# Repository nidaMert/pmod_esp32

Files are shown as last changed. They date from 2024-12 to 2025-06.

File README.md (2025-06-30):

# MuhTas-1 Project PMOD ESP32

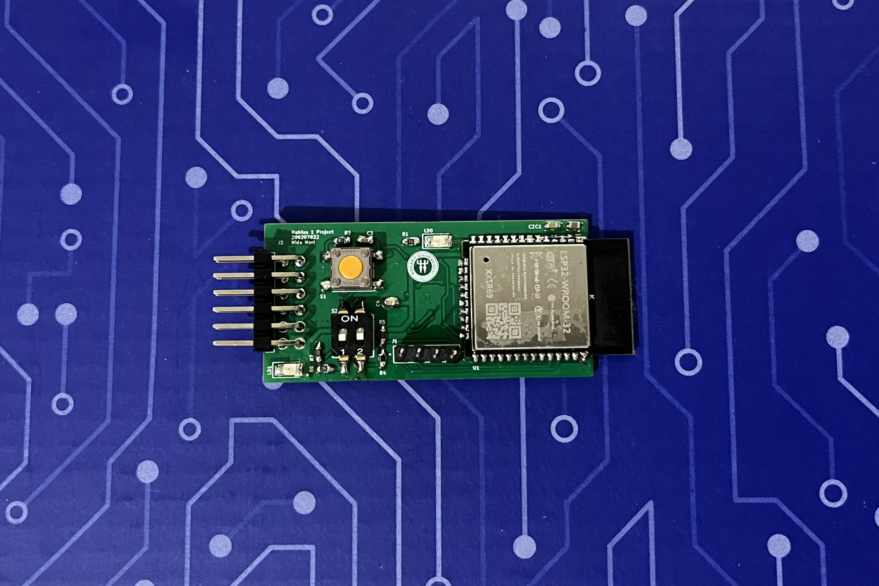
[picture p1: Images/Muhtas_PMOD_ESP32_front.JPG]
image alt


**Overview**
---
This project focuses on the design and testing of a custom 2-layer PMOD ESP32 module, closely resembling Digilent's PMOD ESP32 product. The PMOD ESP32 module provides Wi-Fi and Bluetooth connectivity, making it an ideal choice for embedded systems and IoT applications that require wireless communication. The module is designed to interface seamlessly with microcontrollers and FPGAs via the PMOD interface, enabling rapid prototyping and testing.

The functionality of the designed PMOD ESP32 board will be verified by sending AT commands through an STM32 microcontroller.

This repository includes:
- **Hardware Design Files** for the custom PMOD ESP32 board.
- **Firmware and Documentation** for the ESP32-WROOM-32 module.
- **Testing Examples** demonstrating STM32-based communication using AT commands.

The project serves as a practical solution for developers seeking an easy-to-use wireless module for their embedded systems.

**Project Structre**
---
- **Documentation/**: Contains connection diagrams for STM32-PMOD ESP32 / PMOD ESP32-USB TTL Converter and datasheets for components.
- **Firmware/ESP32-WROOM-32-AT-V3.4.0.0/**: Includes ESP32 Wroom 32 firmware files, user guides, release notes, and other documentation related to ESP32-WROOM-32-AT V3.4.0.0.
- **Hardware Designs/**: Contains hardware design files for the PMOD ESP32 module in 2-layer and 4-layer configurations.
- **Images/**: The photos of the PMOD ESP32 module before and after soldering, as well as the photos of the completed connections, are located in this folder.
- **Library/**: The libraries of components that are necessary for the project but are not available in the KiCad library are located in this folder.
- **STM32 Applications/**: Includes STM32 Cube IDE application and logic analyzer test results.
- **.gitmodules**: Configuration file for Git submodules.
- **README.md**: This file provides an overview of the project and instructions.

**Version Comparison**
---
- Between v0.1 and v0.2 of the PCB, the only difference lies in the routing; in v0.2, the placement and number of vias were optimized to enhance signal integrity and streamline the overall layout.
- **Branch Links of Versions** :  
[PMOD_ESP32_2Layers_v0.1](https://github.com/nidaMert/pmod_esp32/tree/PMOD_ESP32_2Layers_v0.1): Initial version of the PCB.  
[PMOD_ESP32_2Layers_v0.2](https://github.com/nidaMert/pmod_esp32/tree/PMOD_ESP32_2Layers_v0.2): Updated version with optimized routing.

**Connection Diagrams**
---
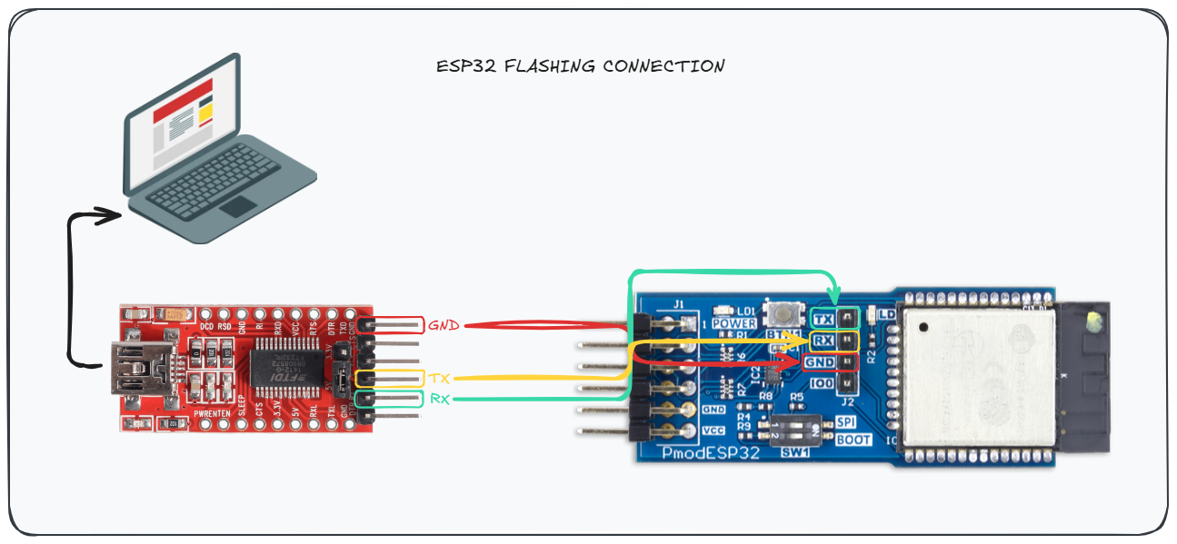
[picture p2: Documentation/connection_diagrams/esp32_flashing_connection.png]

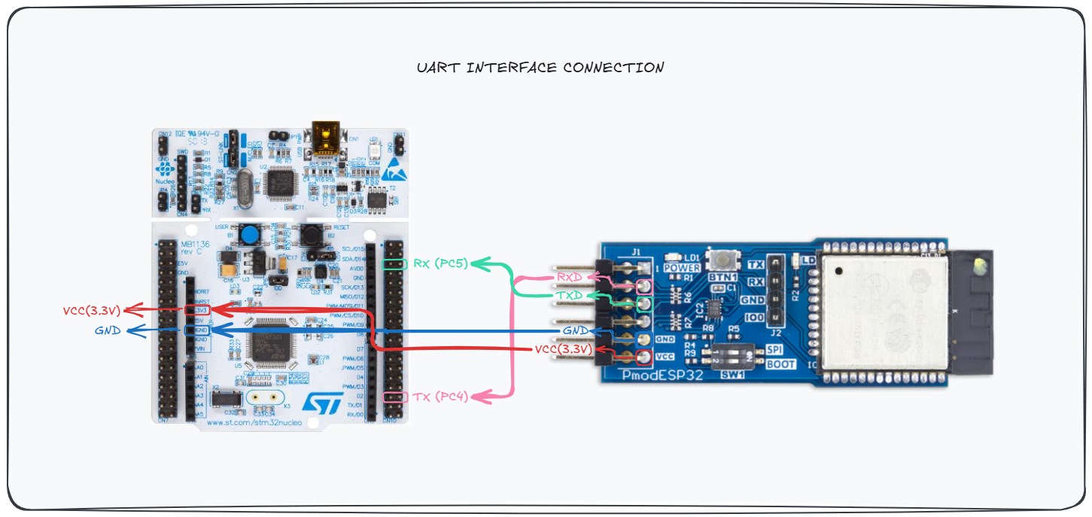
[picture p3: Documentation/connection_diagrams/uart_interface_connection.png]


**References**
---
This project was developed based on the Digilent product: [[here](https://digilent.com/reference/pmod/pmodesp32/start?redirect=1)]. The design and implementation closely resemble this product, with some modifications.

**Educational Use Only**
---
All contents of this project are shared solely for individual learning and academic evaluation. Copying, redistribution, or reuse in other projects is **strictly prohibited**.

**© Copyright**
---
**Copyright (c) 2025 Nida Mert**

All rights reserved. The source files, documentation, and visuals are provided strictly for educational and personal review purposes only.

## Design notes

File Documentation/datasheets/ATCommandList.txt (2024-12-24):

---Basic AT Commands---
AT						//Test AT startup
AT+RST						//Restart a modüle
AT+GMR						//Check version information

---Wi-Fi AT Commands---
AT+CWLAP					//List all available APs.
AT+CWQAP					//Disconnect from an AP.
AT+CWSTATE?					//Query the Wi-Fi state and Wi-Fi info
						//current Wi-Fi state
				  			0: ESP32 station has not started any Wi-Fi connection.
				  			1: ESP32 station has connected to an AP, but does not get an IPv4 address yet.
				  			2: ESP32 station has connected to an AP, and got an IPv4 address.
				  			3: ESP32 station is in Wi-Fi connecting or reconnecting state.
				  			4: ESP32 station is in Wi-Fi disconnected state.
AT+CWMODE?					//Query the Wi-Fi mode of ESP32.
						//<mode>
				 			0: Null mode. Wi-Fi RF will be disabled. The ESP32 will automatically connect to an AP if the configuration to connect to the AP has already been saved in flash before.
				  			1: Station mode.
				  			2: SoftAP mode.
				  			3: SoftAP+Station mode.
AT+CWMODE=<mode>
AT+CWJAP?					//Query the AP to which the ESP32 Station is already connected.
AT+CWJAP=[<ssid>],[<pwd>]			//Connect an ESP32 station to a targeted AP.
AT+CWJAP					//Connect an ESP32 station to a targeted AP with last Wi-Fi configuration.
						//<error code>
				  			1: connection timeout.
				  			2: wrong password.
				  			3: cannot find the target AP.
				  			4: connection failed.
				  			others: unknown error occurred.
AT+CIPV6=1					// At present, ESP-AT is mainly based on IPv4 network, supplemented by IPv6 network.To get an IPv6 address, we need to set it.
AT+CIPSTA?					//Query the IP address of the ESP32 Station.

---TCP/IP AT Commands---
AT+CIPSTART					//Establish TCP Connection
						//Single connection (AT+CIPMUX=0):
				  			AT+CIPSTART=<"type">,<"remote host">,<remote port>[,<keep_alive>][,<"local IP">][,<timeout>]
				  			Multiple Connections (AT+CIPMUX=1):
				  			AT+CIPSTART=<link ID>,<"type">,<"remote host">,<remote port>[,<keep_alive>][,<"local IP">][,<timeout>]
AT+CIPSTATE?					//Obtain the TCP/UDP/SSL Connection Information

---TCP Client Commands---
AT+CIPSTART="TCP","192.168.1.57",8080		//TCP Client olarak bağlan
AT+CIPMODE=1					//Transparan mod aktif
AT+CIPSEND					//Veri gönder
"+++"						//Transparan komut göndermeyi bitir.
AT+CIPCLOSE					//Bağlantıyı kes.

---TCP Server Commands---
AT+CIPMUX=1					//Birden fazla bağlantıya izin ver.
AT+CIPSERVER=1,80				//80 numaralı TCP portunu aç
AT+CIPSEND=0,10					//10 Byte veri gönder
AT+CIPCLOSE=0					//bağlantıyı kes

---UDP Client/Server Commands---
AT+CIPSTART="UDP","192.168.1.57",1001,2001,0
AT+CIPMODE=1					//Transparan mod aktif
AT+CIPSEND					//Veri gönder
"+++"						//Transparan komut göndermeyi bitir.
AT+CIPCLOSE					//Bağlantıyı kes.

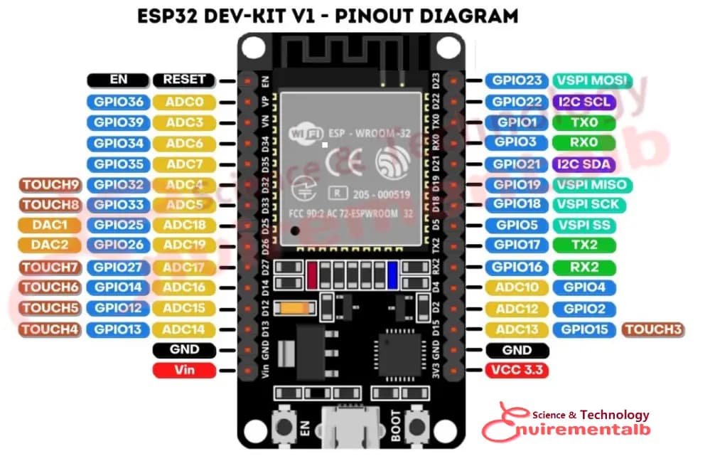
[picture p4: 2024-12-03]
Documentation/datasheets/esp32 devkit pinout.jpeg

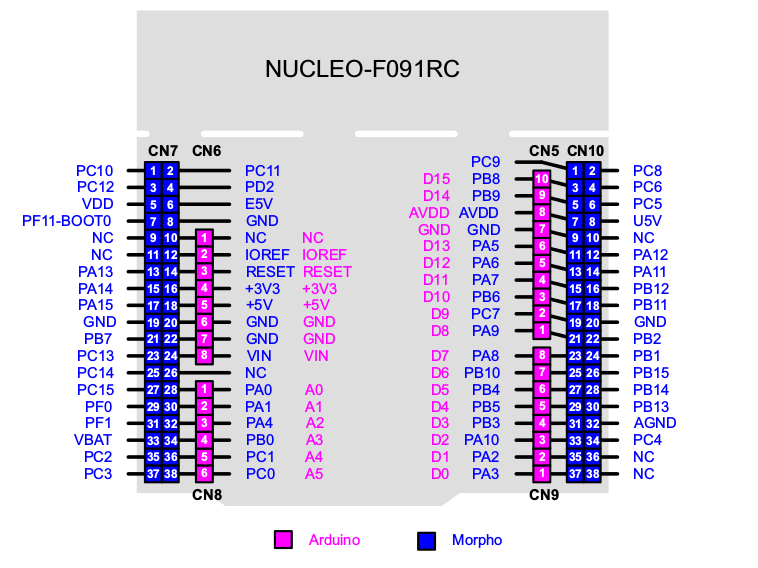
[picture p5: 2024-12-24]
Documentation/datasheets/nucleo-f091_pinout.png

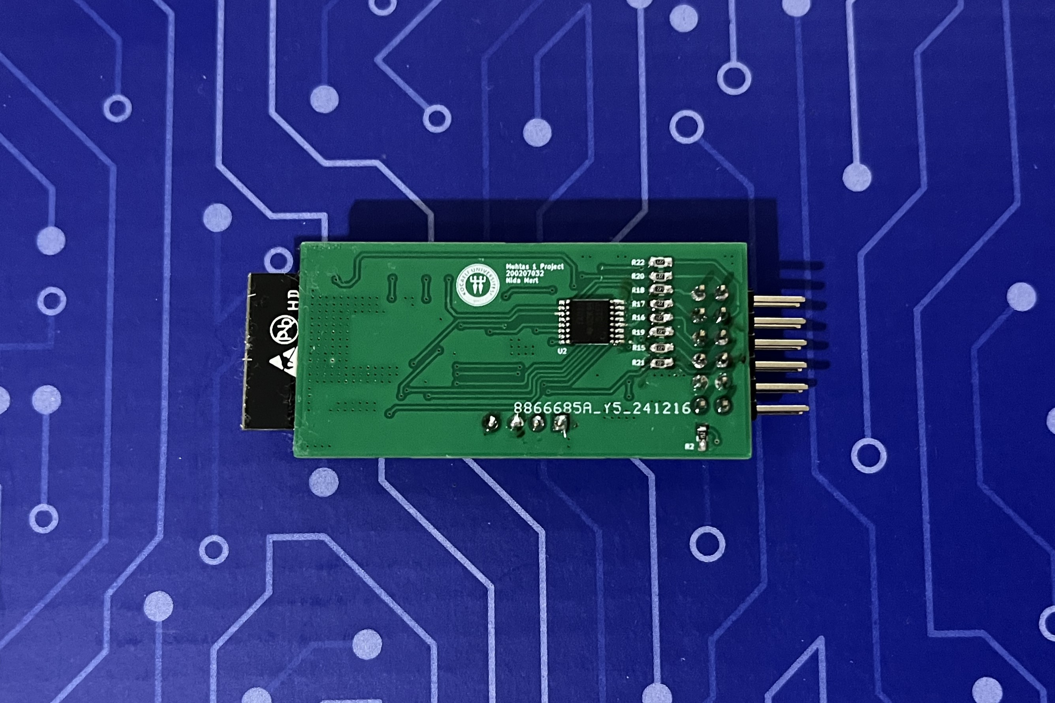
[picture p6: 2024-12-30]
Images/Muhtas1_PMOD_ESP32_back_.JPG

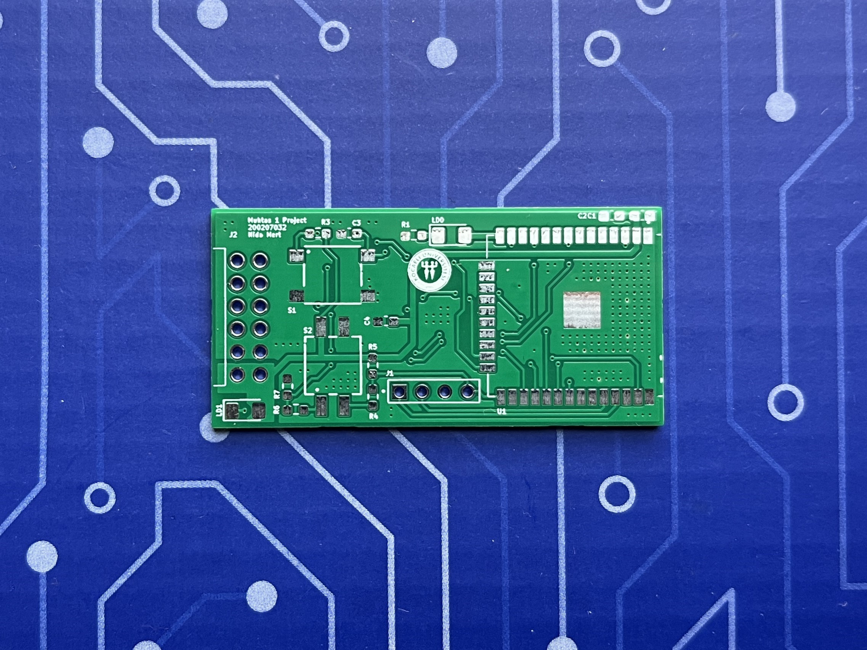
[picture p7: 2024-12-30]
Images/PCB_front.JPG

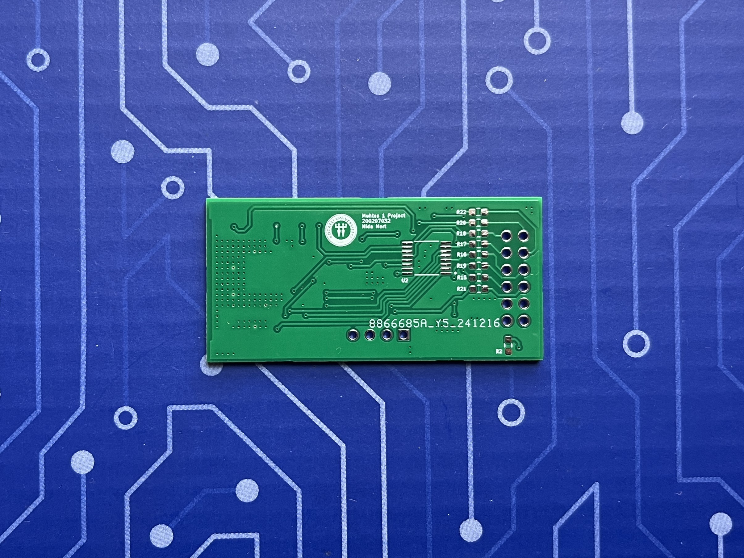
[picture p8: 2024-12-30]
Images/PCB_back.JPG

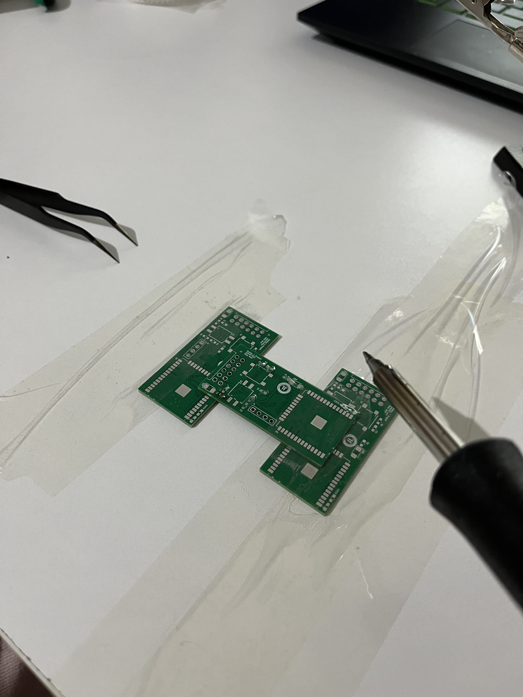
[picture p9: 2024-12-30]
Images/Lehimleme.JPG

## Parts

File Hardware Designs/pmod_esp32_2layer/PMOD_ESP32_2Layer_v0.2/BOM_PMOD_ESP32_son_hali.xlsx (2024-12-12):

Reference | Value | Datasheet | Qty | MANUFACTURER | PACKAGE | Price | Description | Website Links to Buy Components
C1 | 10uF | https://cdn.ozdisan.com/ETicaret_Dosya/1078246_1413433342..pdf | 1 | Viking | 603 | 0.23 TL | Unpolarized capacitor, small symbol | https://www.ozdisan.com/Product/Detail/1057176/MCF03MTX250106
C2,C4,C5 | 100nF | https://www.mouser.com.tr/datasheet/2/585/MLCC-1837944.pdf | 3 | Samsung | 603 | 0.21 TL | Unpolarized capacitor, small symbol | https://www.direnc.net/100nf-50v-603-smd-kondansator
C3 | 10nF | https://www.mouser.com.tr/datasheet/2/585/MLCC_Automotive-1837966.pdf | 1 | Samsung | 603 | 0.14 TL | Unpolarized capacitor, small symbol | https://www.direnc.net/10nf-50v-10-x7r-603-smd-kondansator
J1 | 4-Pin Male Header, THT | https://pdf.direnc.net/upload/5-pin-1x5-2-54mm-erkek-pin-header-tht-datasheet.pdf | 1 | Connfly |  | 6.59 TL | 5-Pin Single Row Male Header, 2.54mm Pitch, Through-Hole Mount | https://www.direnc.net/5-pin-1x5-254mm-erkek-pin-header-tht
J2 | 2x6 Pin Male Header, THT | https://pdf.direnc.net/upload/20-pin-2x10-2-54mm-erkek-pin-header-tht-90c-datasheet.pdf | 1 | Connfly |  | 5.99 TL | 2.54mm (0.1") Pitch DIL Horizontal Throughboard Pin Header, 5.8mm mating pin height, selective gold + tin, 6+6 contacts | https://www.direnc.net/20-pin-2x10-254mm-erkek-pin-header-tht-90c
LD0 | Green Led | https://pdf.direnc.net/upload/dstk6802-datasheet.pdf | 1 | Honglitronic | 1206 | 0.81 TL | Light emitting diode (green led) | https://www.direnc.net/1206-kilif-smd-yesil-led-600mcd-honglitronic
LD1 | Red Led | https://pdf.direnc.net/upload/dstk6799-datasheet.pdf | 1 | Honglitronic | 1206 | 0.94 TL | Light emitting diode (red led) | https://www.direnc.net/1206-kilif-smd-kirmizi-led-100mcd-honglitronic
R1,R2 | 1.5K | https://cdn.ozdisan.com/ETicaret_Dosya/399380_9872459.pdf | 2 | ROYALOHM | 603 | 0.00032 TL | 1.5K Resistor | https://www.ozdisan.com/Product/Detail/336236/0603SAJ0152T5E
R3 | 10K | https://cdn.ozdisan.com/ETicaret_Dosya/399380_9872459.pdf | 1 | ROYALOHM | 603 | 0.06 TL | 10K Resistor | https://www.direnc.net/10k-5-110w-s-603-smd-direnc-5000-adet
R4 | 1K | https://cdn.ozdisan.com/ETicaret_Dosya/399380_9872459.pdf | 1 | ROYALOHM | 603 | 0.06 TL | 1K Resistor | https://www.direnc.net/1k-5-110w-s-603-smd-direnc-5000-adet
R5,R7 | 20K | https://cdn.ozdisan.com/ETicaret_Dosya/399380_9872459.pdf | 2 | ROYALOHM | 603 | 0.06 TL | 20K Resistor | https://www.direnc.net/0603-20k-ohms-1-1/10w-s-100ppm
R6 | 5.6K | https://cdn.ozdisan.com/ETicaret_Dosya/399380_9872459.pdf | 1 | ROYALOHM | 603 | 0.00032 TL | 5.6K Resistor | https://www.ozdisan.com/Product/Detail/336242/0603SAJ0562T5E
R15,R16,R17,R18,R19,R20,R21,R22 | 200 | https://cdn.ozdisan.com/ETicaret_Dosya/399380_9872459.pdf | 8 | ROYALOHM | 603 | 0.05 TL | 200 Ohm Resistor | https://www.direnc.net/220r-5-110w-s-603-smd-direnc-5000-adet
S1 | Tactile Switch | https://cdn.ozdisan.com/ETicaret_Dosya/596313_168110.pdf | 1 | Würth |  | 7.75 TL | SWITCH TACTILE SPST-NO 0.05A 12V | https://www.ozdisan.com/electromechanical-components/switches/tactile-switches/DTSM-61S-V-TR/396752
S2 | Dip Switch | https://cdn.ozdisan.com/ETicaret_Dosya/649724_1913908935..pdf | 1 | Würth |  | 65.07 TL | SWITCH DIP 2 WAY BLACK SMT V/T | https://www.ozdisan.com/Product/Detail/649724/418121270802
S3,S4 | SPDT Analog Switch | https://www.ti.com/lit/ds/symlink/ts3a5018.pdf?HQS=dis-dk-null-digikeymode-dsf-pf-null-wwe&ts=1733755876897 | 2 | Texas Instruments |  | 24.86 TL | IC SWITCH SPDT X 2 10OHM 10VSSOP | https://www.entegreci.com/urun/ts3a5018pwr/
U1 | ESP-WROOM-32 | https://www.mouser.com/datasheet/2/891/esp-wroom-32_datasheet_en-1223836.pdf | 1 | Espressif Systems |  | 125.56 TL | ESP-WROOM-32 4Mbit Flash WiFi ve Bluetooth Modül | https://www.direnc.net/esp-wroom32-modul

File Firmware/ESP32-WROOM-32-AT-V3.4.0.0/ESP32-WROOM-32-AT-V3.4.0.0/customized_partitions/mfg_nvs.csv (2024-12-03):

key | type | encoding | value
server_cert | namespace
server_cert | file | binary | /builds/application/esp-at/components/customized_partitions/raw_data/server_cert/server_cert.crt
server_key | namespace
server_key | file | binary | /builds/application/esp-at/components/customized_partitions/raw_data/server_key/server.key
server_ca | namespace
server_ca | file | binary | /builds/application/esp-at/components/customized_partitions/raw_data/server_ca/server_ca.crt
client_cert | namespace
client_cert.0 | file | binary | /builds/application/esp-at/components/customized_partitions/raw_data/client_cert/client_cert_00.crt
client_cert.1 | file | binary | /builds/application/esp-at/components/customized_partitions/raw_data/client_cert/client_cert_01.crt
client_key | namespace
client_key.0 | file | binary | /builds/application/esp-at/components/customized_partitions/raw_data/client_key/client_key_00.key
client_key.1 | file | binary | /builds/application/esp-at/components/customized_partitions/raw_data/client_key/client_key_01.key
client_ca | namespace
client_ca.0 | file | binary | /builds/application/esp-at/components/customized_partitions/raw_data/client_ca/client_ca_00.crt
client_ca.1 | file | binary | /builds/application/esp-at/components/customized_partitions/raw_data/client_ca/client_ca_01.crt
mqtt_cert | namespace
mqtt_cert | file | binary | /builds/application/esp-at/components/customized_partitions/raw_data/mqtt_cert/mqtt_client.crt
mqtt_key | namespace
mqtt_key | file | binary | /builds/application/esp-at/components/customized_partitions/raw_data/mqtt_key/mqtt_client.key
mqtt_ca | namespace
mqtt_ca | file | binary | /builds/application/esp-at/components/customized_partitions/raw_data/mqtt_ca/mqtt_ca.crt
factory_param | namespace
version | data | i8 | 4
module_name | data | string | WROOM-32
max_tx_power | data | i8 | 78
country_code | data | string | CN
start_channel | data | u8 | 1
channel_num | data | u8 | 13
uart_port | data | i8 | 1
uart_baudrate | data | i32 | 115200
uart_tx_pin | data | i32 | 17
uart_rx_pin | data | i32 | 16
uart_cts_pin | data | i32 | 15
uart_rts_pin | data | i32 | 14
ble_data | namespace
cfg0 | data | string | 0,16,0x2800,0x01,2,2,A002
cfg1 | data | string | 1,16,0x2803,0x01,1,1,02
cfg2 | data | string | 2,16,0xC300,0x01,1,1,30
cfg3 | data | string | 3,16,0x2901,0x11,1,1,30
cfg4 | data | string | 4,16,0x2803,0x01,1,1,02
cfg5 | data | string | 5,16,0xC301,0x01,512,512,
cfg6 | data | string | 6,16,0x2901,0x11,512,512,
cfg7 | data | string | 7,16,0x2803,0x01,1,1,08
cfg8 | data | string | 8,16,0xC302,0x10,1,1,30
cfg9 | data | string | 9,16,0x2901,0x01,1,1,01
cfg10 | data | string | 10,16,0x2803,0x01,1,1,04
cfg11 | data | string | 11,16,0xC303,0x10,1,1,30
cfg12 | data | string | 12,16,0x2901,0x10,1,1,30
cfg13 | data | string | 13,16,0x2803,0x01,1,1,08
cfg14 | data | string | 14,16,0xC304,0x10,512,512,
cfg15 | data | string | 15,16,0x2803,0x01,1,1,10
cfg16 | data | string | 16,16,0xC305,0x01,1,1,00
cfg17 | data | string | 17,16,0x2902,0x11,2,2,0000
cfg18 | data | string | 18,16,0x2803,0x01,1,1,20
cfg19 | data | string | 19,16,0xC306,0x01,1,1,00
cfg20 | data | string | 20,16,0x2902,0x11,2,2,0000
cfg21 | data | string | 21,16,0x2803,0x01,1,1,02
cfg22 | data | string | 22,16,0xC307,0x01,1,1,30
cfg23 | data | string | 23,16,0x2901,0x11,256,1,30
cfg24 | data | string | 24,16,0x2800,0x01,2,2,A003
cfg25 | data | string | 25,16,0x2803,0x01,1,1,02
cfg26 | data | string | 26,16,0xC400,0x01,1,1,30
cfg27 | data | string | 27,16,0x2901,0x11,1,1,30
cfg28 | data | string | 28,16,0x2803,0x01,1,1,02
cfg29 | data | string | 29,16,0xC401,0x01,1,1,30
cfg30 | data | string | 30,16,0x2901,0x11,256,1,30

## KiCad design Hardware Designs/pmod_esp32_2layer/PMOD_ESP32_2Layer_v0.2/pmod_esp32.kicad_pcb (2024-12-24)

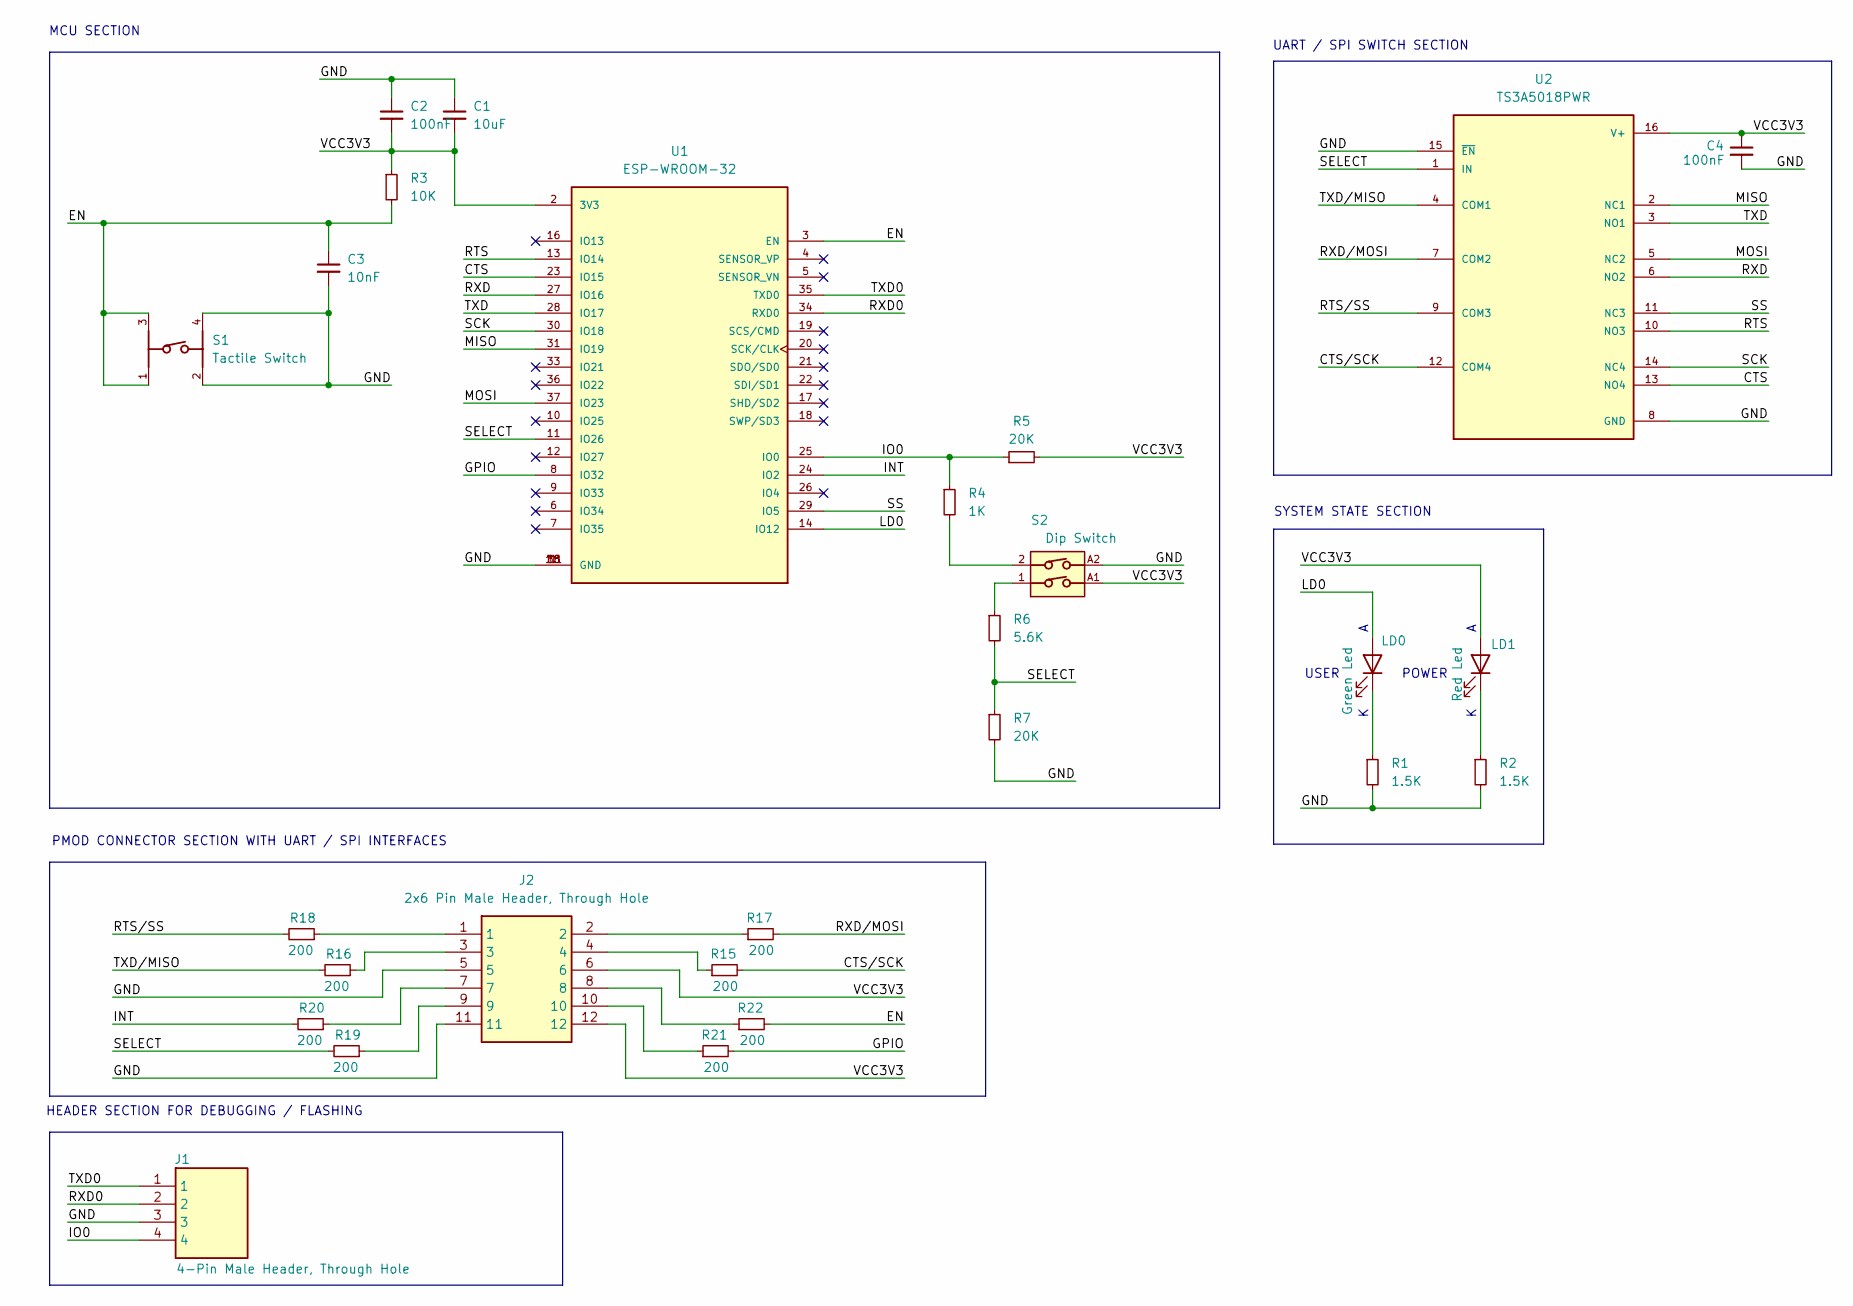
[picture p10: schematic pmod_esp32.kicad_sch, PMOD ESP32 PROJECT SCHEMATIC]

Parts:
C1: 10uF; C_0603_1608Metric_Pad1.08x0.95mm_HandSolder
C2, C4: 100nF; C_0603_1608Metric_Pad1.08x0.95mm_HandSolder
C3: 10nF; C_0603_1608Metric_Pad1.08x0.95mm_HandSolder
J1: 4-Pin Male Header, Through Hole; HDRV4W67P0X254_1X4_1016X241X858P; PARTREV DG
J2: 2x6 Pin Male Header, Through Hole; M209740642; Manufacturer_Part_Number M20-9740642; Mouser Part Number 855-M20-9740642
LD0: Green Led; LED_1206_3216Metric_Pad1.42x1.75mm_HandSolder
LD1: Red Led; LED_1206_3216Metric_Pad1.42x1.75mm_HandSolder
R1, R2: 1.5K; R_0603_1608Metric_Pad0.98x0.95mm_HandSolder
R3: 10K; R_0603_1608Metric_Pad0.98x0.95mm_HandSolder
R4: 1K; R_0603_1608Metric_Pad0.98x0.95mm_HandSolder
R5, R7: 20K; R_0603_1608Metric_Pad0.98x0.95mm_HandSolder
R6: 5.6K; R_0603_1608Metric_Pad0.98x0.95mm_HandSolder
R15, R16, R17, R18, R19, R20, R21, R22: 200; R_0603_1608Metric_Pad0.98x0.95mm_HandSolder
S1: Tactile Switch; 430182050816; PART-NUMBER 430182050816
S2: Dip Switch; 418121270802; PART-NUMBER 418121270802
U1: ESP-WROOM-32; MODULE_ESP-WROOM-32
U2: TS3A5018PWR; SOP65P640X120-16N; PARTREV H

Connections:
/CTS: U1.23 (IO15), U2.13 (NO4)
/CTS/SCK: R15.2, U2.12 (COM4)
/EN: C3.1, R3.2, R22.2, S1.1, S1.3, U1.3 (EN)
/GND: C1.1, C2.1, C3.2, C4.2, J1.3, J2.5, J2.11, R1.2, R2.2, R7.2, S1.2, S1.4, S2.A2, U1.1 (GND), U1.1.1 (GND), U1.15 (GND), U1.38 (GND), U2.8 (GND), U2.15 (~EN)
/GPIO: R21.2, U1.8 (IO32)
/INT: R20.2, U1.24 (IO2)
/IO0: J1.4, R4.1, R5.1, U1.25 (IO0)
/LD0: LD0.2 (A), U1.14 (IO12)
/MISO: U1.31 (IO19), U2.2 (NC1)
/MOSI: U1.37 (IO23), U2.5 (NC2)
/RTS: U1.13 (IO14), U2.10 (NO3)
/RTS/SS: R18.2, U2.9 (COM3)
/RXD: U1.27 (IO16), U2.6 (NO2)
/RXD0: J1.2, U1.34 (RXD0)
/RXD/MOSI: R17.2, U2.7 (COM2)
/SCK: U1.30 (IO18), U2.14 (NC4)
/SELECT: R6.2, R7.1, R19.2, U1.11 (IO26), U2.1 (IN)
/SS: U1.29 (IO5), U2.11 (NC3)
/TXD: U1.28 (IO17), U2.3 (NO1)
/TXD0: J1.1, U1.35 (TXD0)
/TXD/MISO: R16.2, U2.4 (COM1)
/VCC3V3: C1.2, C2.2, C4.1, J2.6, J2.12, LD1.2 (A), R3.1, R5.2, S2.A1, U1.2 (3V3), U2.16 (V+)
unnamed: J2.1, R18.1
unnamed: J2.2, R17.1
unnamed: J2.3, R16.1
unnamed: J2.4, R15.1
unnamed: J2.7, R20.1
unnamed: J2.8, R22.1
unnamed: J2.9, R19.1
unnamed: J2.10, R21.1
unnamed: LD0.1 (K), R1.1
unnamed: LD1.1 (K), R2.1
unnamed: R4.2, S2.2
unnamed: R6.1, S2.1

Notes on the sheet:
POWER
PMOD CONNECTOR SECTION WITH UART / SPI INTERFACES
SYSTEM STATE SECTION
UART / SPI SWITCH SECTION
USER
HEADER SECTION FOR DEBUGGING / FLASHING
MCU SECTION

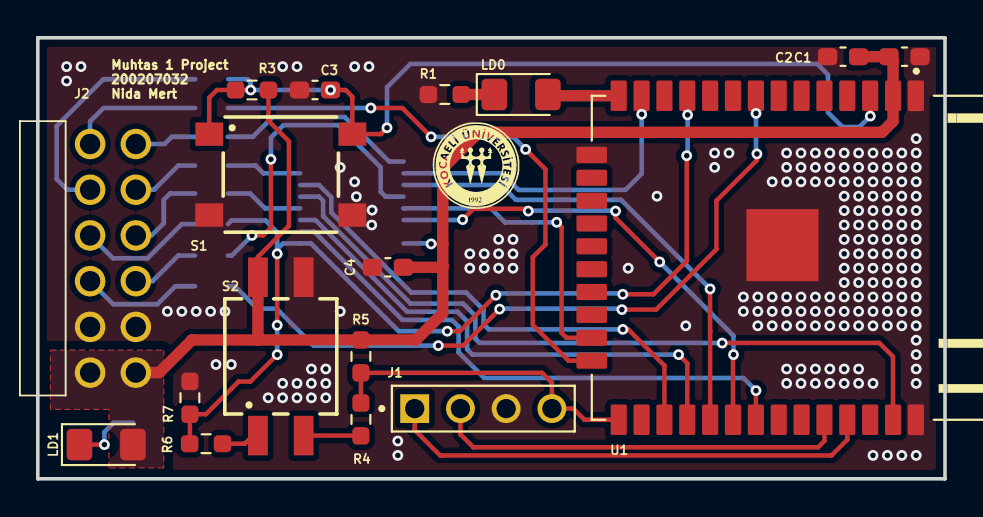
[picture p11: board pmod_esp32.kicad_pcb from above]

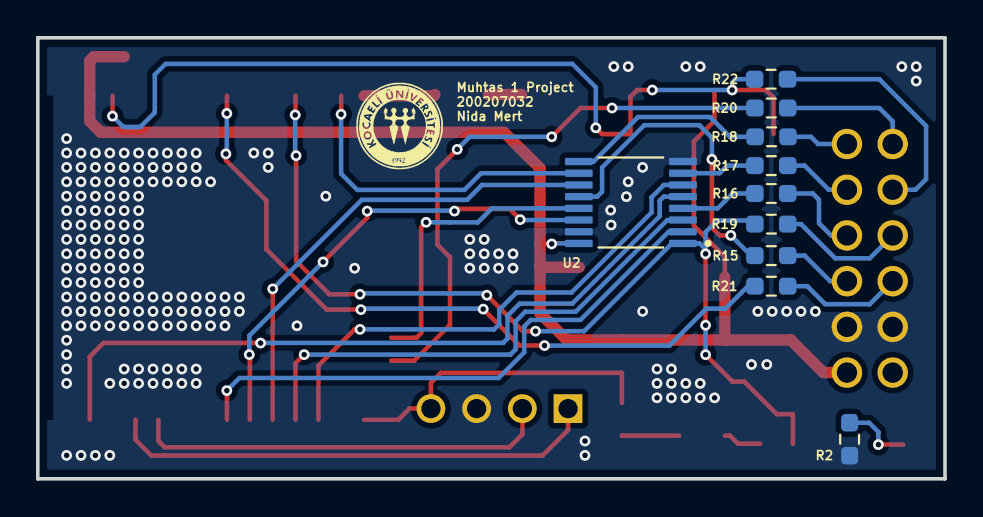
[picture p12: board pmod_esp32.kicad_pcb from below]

Board: 2 copper layers, 50.4 x 24.5 mm, 27 parts (10 on the bottom side), 34 nets.

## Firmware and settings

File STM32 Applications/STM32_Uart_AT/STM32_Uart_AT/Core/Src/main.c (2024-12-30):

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
/* Includes ------------------------------------------------------------------*/
#include "main.h"
#include "dma.h"
#include "usart.h"
#include "gpio.h"

/* USER CODE BEGIN Includes */
#include "atc.h"
/* USER CODE END Includes */


/* USER CODE BEGIN PV */
#define RX_BUFFER_SIZE 512
#define TX_BUFFER_SIZE 512

char rx_buffer[RX_BUFFER_SIZE];
char tx_buffer[TX_BUFFER_SIZE];

UART_HandleTypeDef huart3;
ATC_HandleTypeDef esp32;  // ESP32 için ATC yapılandırması
/* USER CODE END PV */

void SystemClock_Config(void);
/* USER CODE BEGIN 0 */
void HAL_UARTEx_RxEventCallback(UART_HandleTypeDef *huart, uint16_t Size)
{
	if (huart->Instance == USART3)
	{
		ATC_IdleLineCallback(&esp32, Size);
	}
}
/* USER CODE END 0 */

/**
  * @brief  The application entry point.
  * @retval int
  */
int main(void)
{

  /* MCU Configuration--------------------------------------------------------*/

  /* Reset of all peripherals, Initializes the Flash interface and the Systick. */
  HAL_Init();

  /* Configure the system clock */
  SystemClock_Config();

  /* Initialize all configured peripherals */
  MX_GPIO_Init();
  MX_DMA_Init();
  MX_USART2_UART_Init();
  MX_USART3_UART_Init();
  /* USER CODE BEGIN 2 */
  // ATC yapılandırmasını başlat
  ATC_Init(&esp32, &huart3, RX_BUFFER_SIZE, "ESP32");
  // Wi-Fi Bağlantısı Kurma
  ATC_SendReceive(&esp32, "AT+RST\r\n", 100, NULL, 100, 2, "\r\nOK\r\n", "\r\nERROR\r\n");
  HAL_Delay(3000);
  ATC_SendReceive(&esp32, "AT+CWQAP\r\n", 100, NULL, 100, 2, "\r\nOK\r\n", "\r\nERROR\r\n");
  HAL_Delay(3000);
  ATC_SendReceive(&esp32, "AT+CWSTATE?\r\n", 100, NULL, 100, 3, "\r\n0\r\n", "\r\n1\r\n", "\r\n2\r\n");
  HAL_Delay(3000);
  ATC_SendReceive(&esp32, "AT+CWMODE=1\r\n", 100, NULL, 100, 2, "\r\nOK\r\n", "\r\nERROR\r\n");
  HAL_Delay(3000);
  ATC_SendReceive(&esp32, "AT+CWJAP=\"FiberHGW_ZYB82A\",\"N3THkAdYRCPF\"\r\n", 100, NULL, 100, 2, "\r\nOK\r\n", "\r\nERROR\r\n");
  HAL_Delay(3000);
  ATC_SendReceive(&esp32, "AT+CWJAP?\r\n", 100, NULL, 100, 2, "\r\nOK\r\n", "\r\nERROR\r\n");
  /* USER CODE END 2 */

  /* Infinite loop */
  /* USER CODE BEGIN WHILE */
  while (1)
  {
    /* USER CODE END WHILE */

    /* USER CODE BEGIN 3 */
  }
  /* USER CODE END 3 */
}

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


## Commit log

2024-12-03 stm32 first commit
2024-12-03 at firmware added
    [mfg_nvs.csv]
2024-12-12 Some issues have been resolved
    [BOM_PMOD_ESP32.xlsx, BOM_PMOD_ESP32_son_hali.xlsx, pmod_esp32.kicad_pcb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]
2024-12-23 The final versions of the PCB designs have been added.
    [pmod_esp32-B_Cu.gbr, pmod_esp32-B_Mask.gbr, pmod_esp32-B_Paste.gbr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]
2024-12-23 The project has been updated to its final version.
    [pmod_esp32.kicad_sch]
2024-12-24 The folders have been organized.
    [BOM_PMOD_ESP32.csv, BOM_PMOD_ESP32_son_hali.xlsx, mfg_nvs.csv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]
2024-12-24 Added version 0.2 PMOD ESP32 2 Layer
    [BOM_PMOD_ESP32.csv, BOM_PMOD_ESP32_son_hali.xlsx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]
2024-12-30 images folder have been added, and made some changes in STM32 Applications folder
    [BOM_PMOD_ESP32.csv, BOM_PMOD_ESP32_son_hali.xlsx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]
2024-12-31 branch links of PCB versions have been added.

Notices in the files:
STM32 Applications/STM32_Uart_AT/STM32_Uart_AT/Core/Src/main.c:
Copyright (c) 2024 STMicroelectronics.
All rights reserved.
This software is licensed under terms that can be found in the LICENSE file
